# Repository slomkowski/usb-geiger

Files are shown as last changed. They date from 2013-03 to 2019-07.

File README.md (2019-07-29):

# USB Geiger counter

2013 Michał Słomkowski

License: GNU GPL v3.0.

This is a repository of a low-cost USB Geiger counter device using STS-5 tube, ATTiny24 and Python-written host software.

Results can be sent to MySQL database, CSV file, ~~xively.com~~ or defined e-mail address if the radiation level is above the defined threshold.

Project was published in Polish hobby electronics periodic: *Elektronika dla Wszystkich* 10/2013, the article [available here](https://serwis.avt.pl/manuals/AVT3074.pdf).

The repository contains:
* *datasheets* - datasheets of components used in the device, especially the Geiger tube
* *firmare* - source code of firmware for ATTiny24, written in C
* *host/geiger-controller* - simple program in C++ for reading data and writing the settings to the device
* *host/geiger-manager* - more complex software written in Python. Periodically reads the data from sensor and sends them to MySQL or CSV file
* *pcb* - printed circuit board layout in Eagle format, schematic in PNG and mirrored board layout for toner transfer

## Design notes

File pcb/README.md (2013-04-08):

USB Geiger counter
==================

2013 Michał Słomkowski

License: GNU GPL v3.0.

This directory holds circuit board files created in Eagle 6 as well as result files: PDF with mirror image and PNG schematic.

Warning! You need commercial version of Eagle to modify the board. Using freeware version, you may be only able to move elements within area of 80 x 100 mm. This restriction doesn't apply to other tasks like printing, exporting or value changing, though.

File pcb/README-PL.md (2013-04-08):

USB Geiger counter
==================

2013 Michał Słomkowski

Licencja GNU GPL wersja 3.0.

Tu znajdują się pliki płytki drukowanej w Eagle wraz z danymi finalnymi: schematem i lustrzanym PDF-em ze wzorem płytki (potrzebnym do termotransferu).

Uwaga! Płytkę można modyfikować tylko w obszarze 80 x 100 mm używając darmowej wersji, więc ewentualne zmiany mogą wymagać komercyjnej wersji Eagle. Ograniczenie nie dotyczy drukowania, eksportu czy zmiany wartości elementów.

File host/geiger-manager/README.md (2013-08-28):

Geiger Manager
==============
2013 Michał Słomkowski
License: GNU General Public License ver.3

This program is a daemon which monitors constantly the radiation measured by USB Geiger device and sends the results to xively.com, MySQL database, CSV file or e-mail. All configuration is stored in the file 'configuration.ini' which is essential to run. Program uses pyusb library and MySQLdb, if MySQL is enabled.

Optional arguments:
*  -h, --help            show this help message and exit
* -c CONFIG, --config CONFIG
                        reads given configuration file
*  -v, --verbose         shows additional information
*  -b, --background      runs as background process
*  -m, --monitor         starts program in monitor mode
*  -s, --status          reads data from Geiger device and leaves (enabled by
                        default)

To start measuring as a daemon, type:
python2 main.py -mb

geiger.sh is a startup script for Debian and derivative systems (like Raspbian). View that file and read the description within to get to know how to use it.

Running on Windows
==================

This program needs Python 2.7 and libraries: pyusb, libusb and MySQL-python if MySQL module will be used.

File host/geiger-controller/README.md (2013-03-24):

USB Geiger counter
2013 Michał Słomkowski

License: GNU GPL v3.0.

Program provides simple command-line interface to all functions of Geiger device. To display the full list, type:

./geiger-controller --help

The program was written in C++ and libusbx, which is a fork of libusb-1.0 and should stay compatible with it. The code was compiled and run on Linux box, but there's should be no problems with running it on Windows. The program is finished, for more advanced functions like logging to cosm.com or SQL database, check Python script in other directory.

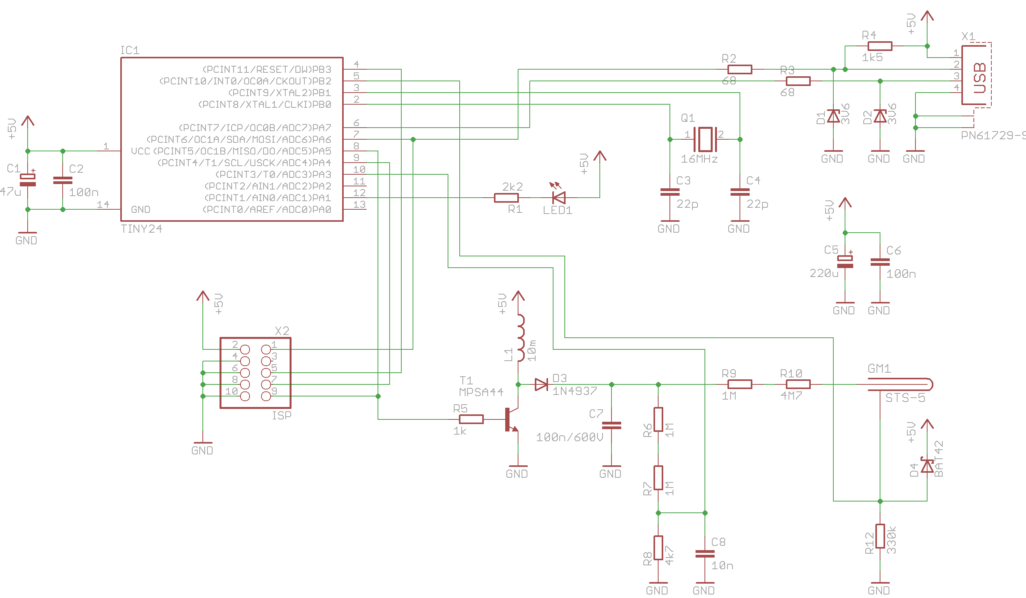
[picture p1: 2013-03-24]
pcb/schematic.png

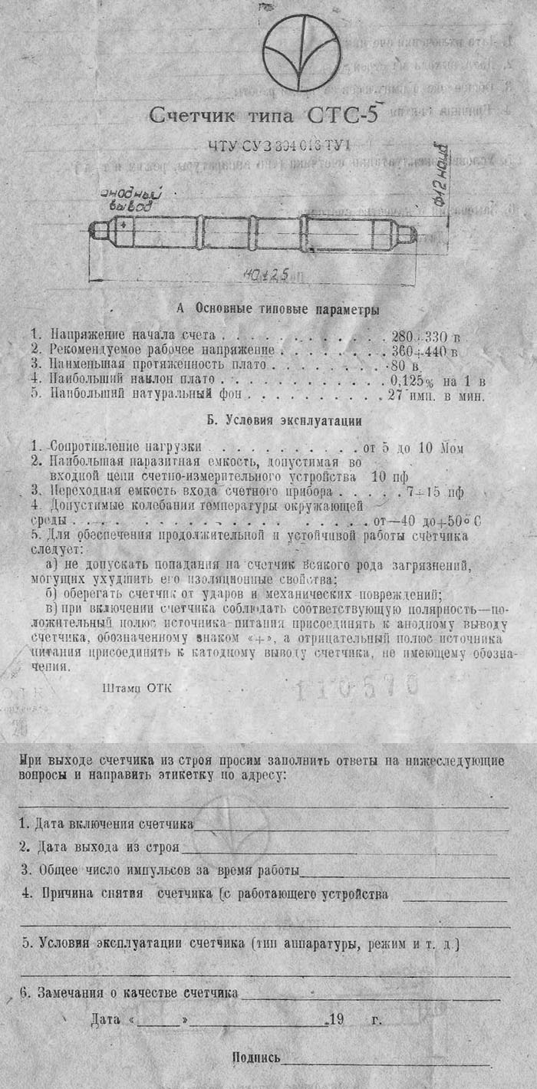
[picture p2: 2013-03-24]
datasheets/sts-5.jpg

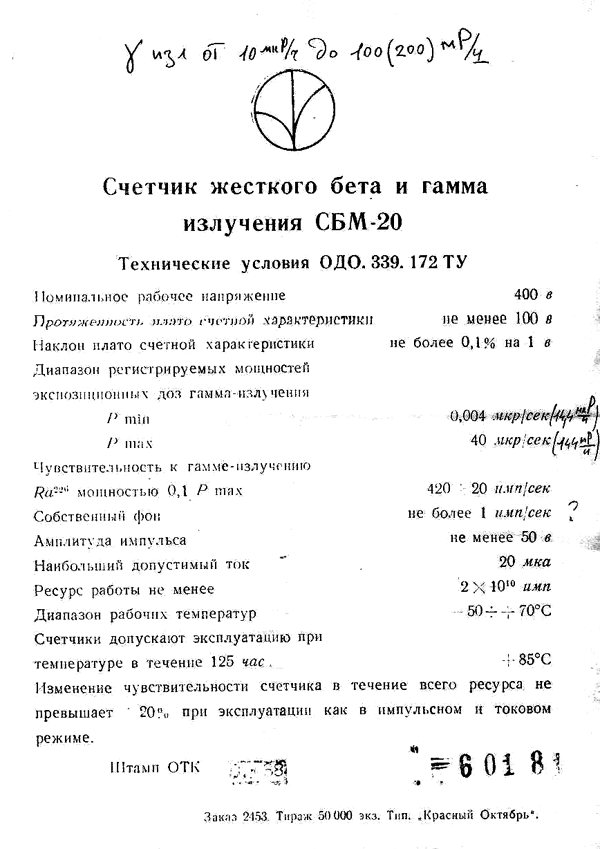
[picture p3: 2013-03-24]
datasheets/sbm-20.png

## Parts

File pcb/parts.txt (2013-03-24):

Partlist

Exported from usb-geiger.sch at 24-03-2013 21:28

EAGLE Version 6.4.0 Copyright (c) 1988-2013 CadSoft

Assembly variant: 

Part     Value          Device            Package      Library  Sheet

C1       47u            CPOL-EUE2.5-6     E2,5-6       rcl      1
C2       100n           C-EU050-025X075   C050-025X075 rcl      1
C3       22p            C-EU025-025X050   C025-025X050 rcl      1
C4       22p            C-EU025-025X050   C025-025X050 rcl      1
C5       220u           CPOL-EUE5-10.5    E5-10,5      rcl      1
C6       100n           C-EU050-025X075   C050-025X075 rcl      1
C7       100n/600V      C-EU225-113X268   C225-113X268 rcl      1
C8       10n            C-EU050-025X075   C050-025X075 rcl      1
D1       3V6            ZENER-DIODEDO34-7 DO34Z7       diode    1
D2       3V6            ZENER-DIODEDO34-7 DO34Z7       diode    1
D3       1N4937         1N4933            DO41-10      diode    1
D4       BAT42          BAT42             DO35-10      diode    1
GM1      STS-5          STS-5             STS-5        geiger   1
IC1      TINY24         TINY24/44/84-PU   DIL14        avr-7    1
L1       10m            L-US0207/5V       0207/5V      rcl      1
LED1                    LED3MM            LED3MM       led      1
Q1       16MHz          XTAL/S            QS           special  1
R1       2k2            R-EU_0207/10      0207/10      rcl      1
R2       68             R-EU_0207/10      0207/10      rcl      1
R3       68             R-EU_0207/10      0207/10      rcl      1
R4       1k5            R-EU_0207/10      0207/10      rcl      1
R5       1k             R-EU_0207/10      0207/10      rcl      1
R6       1M             R-EU_0207/10      0207/10      rcl      1
R7       1M             R-EU_0207/10      0207/10      rcl      1
R8       4k7            R-EU_0207/10      0207/10      rcl      1
R9       1M             R-EU_0207/10      0207/10      rcl      1
R10      4M7            R-EU_0207/10      0207/10      rcl      1
R12      330k           R-EU_0207/10      0207/10      rcl      1
T1       MPSA44         MPSA44            TO92-EBC     geiger   1
X1       PN61729-S      PN61729-S         PN61729-S    con-berg 1
X2                      PINHD-2X5         2X05         pinhead  1

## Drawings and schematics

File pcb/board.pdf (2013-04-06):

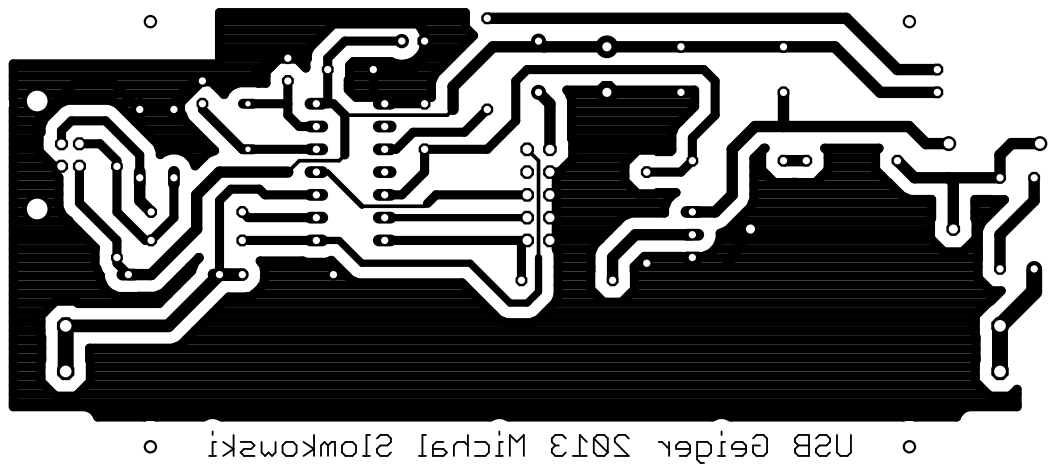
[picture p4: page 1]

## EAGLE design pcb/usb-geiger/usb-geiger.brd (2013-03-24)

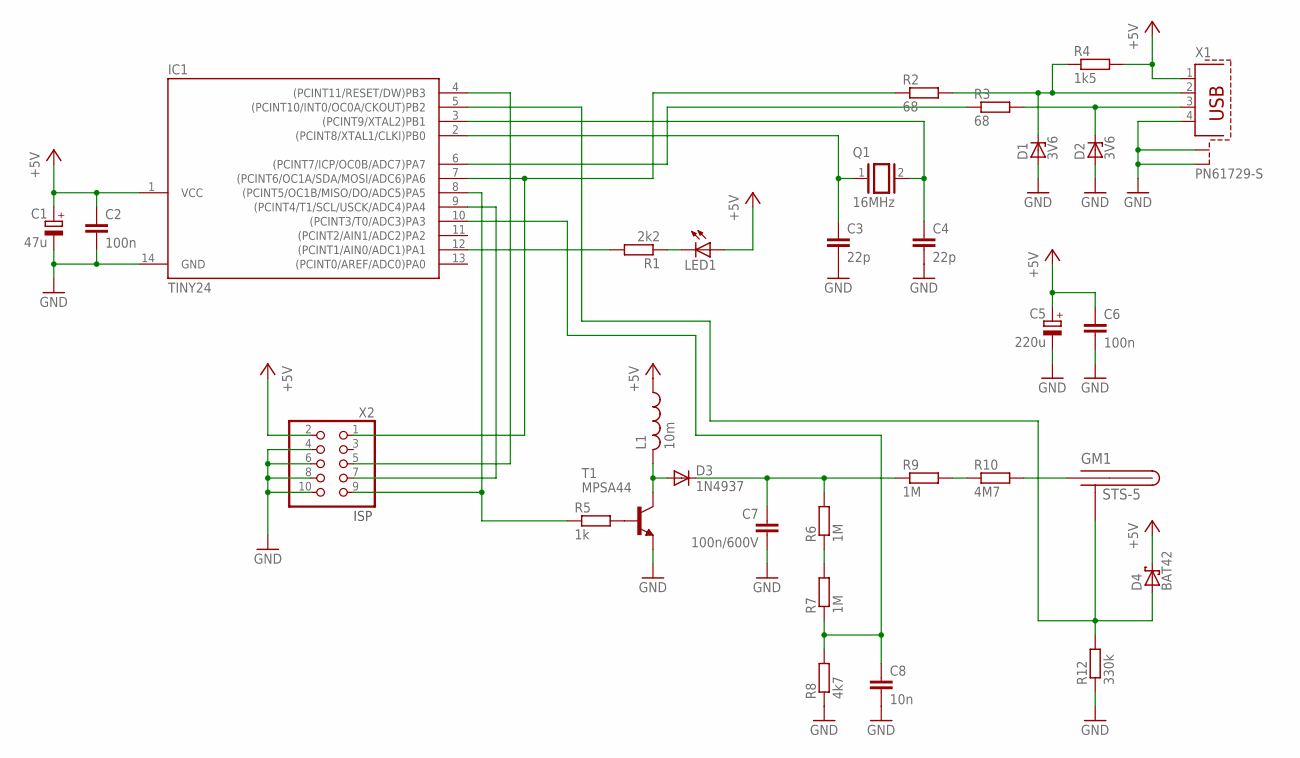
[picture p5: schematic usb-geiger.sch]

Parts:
C1: 47u; E2,5-6
C2, C6: 100n; C050-025X075
C3, C4: 22p; C025-025X050
C5: 220u; E5-10,5
C7: 100n/600V; C225-113X268
C8: 10n; C050-025X075
D1, D2: 3V6; DO34Z7
D3: 1N4937; DO41-10
D4: BAT42; DO35-10
GM1: STS-5
IC1: TINY24; DIL14
L1: 10m; 0207/5V
LED1: LED3MM
Q1: 16MHz; QS
R1: 2k2; 0207/10
R2, R3: 68; 0207/10
R4: 1k5; 0207/10
R5: 1k; 0207/10
R6, R7, R9: 1M; 0207/10
R8: 4k7; 0207/10
R10: 4M7; 0207/10
R12: 330k; 0207/10
T1: MPSA44; TO92-EBC
X1: PN61729-S
X2: PINHD-2X5; 2X05

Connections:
+5V: C1.+, C2.1, C5.+, C6.1, D4.C, IC1.1 (VCC), L1.1, LED1.A, R4.2, X1.1, X2.2
GND: C1.-, C2.2, C3.2, C4.2, C5.-, C6.2, C7.2, C8.2, D1.A, D2.A, IC1.14 (GND), R8.1, R12.1, T1.E, X1.4, X1.S1, X1.S2, X2.4, X2.6, X2.8, X2.10
unnamed: R6.1, R7.2
unnamed: D3.A, L1.2, T1.C
unnamed: R5.2, T1.B
unnamed: C7.1, D3.C, R6.2, R9.1
unnamed: R9.2, R10.1
unnamed: GM1.PLUS1 (PLUS), GM1.PLUS2 (PLUS), R10.2
unnamed: C8.1, IC1.10 ((PCINT3/T0/ADC3)PA3), R7.1, R8.2
unnamed: IC1.6 ((PCINT7/ICP/OC0B/ADC7)PA7), R3.1
unnamed: D4.A, GM1.MINUS1 (MINUS), GM1.MINUS2 (MINUS), IC1.5 ((PCINT10/INT0/OC0A/CKOUT)PB2), R12.2
unnamed: IC1.8 ((PCINT5/OC1B/MISO/DO/ADC5)PA5), R5.1, X2.9
unnamed: IC1.7 ((PCINT6/OC1A/SDA/MOSI/ADC6)PA6), R2.1, X2.1
unnamed: IC1.4 ((PCINT11/RESET/DW)PB3), X2.5
unnamed: IC1.9 ((PCINT4/T1/SCL/USCK/ADC4)PA4), X2.7
unnamed: D1.C, R2.2, R4.1, X1.2
unnamed: D2.C, R3.2, X1.3
unnamed: C4.1, IC1.3 ((PCINT9/XTAL2)PB1), Q1.2
unnamed: C3.1, IC1.2 ((PCINT8/XTAL1/CLKI)PB0), Q1.1
unnamed: IC1.12 ((PCINT1/AIN0/ADC1)PA1), R1.2
unnamed: LED1.K (C), R1.1

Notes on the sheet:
ISP

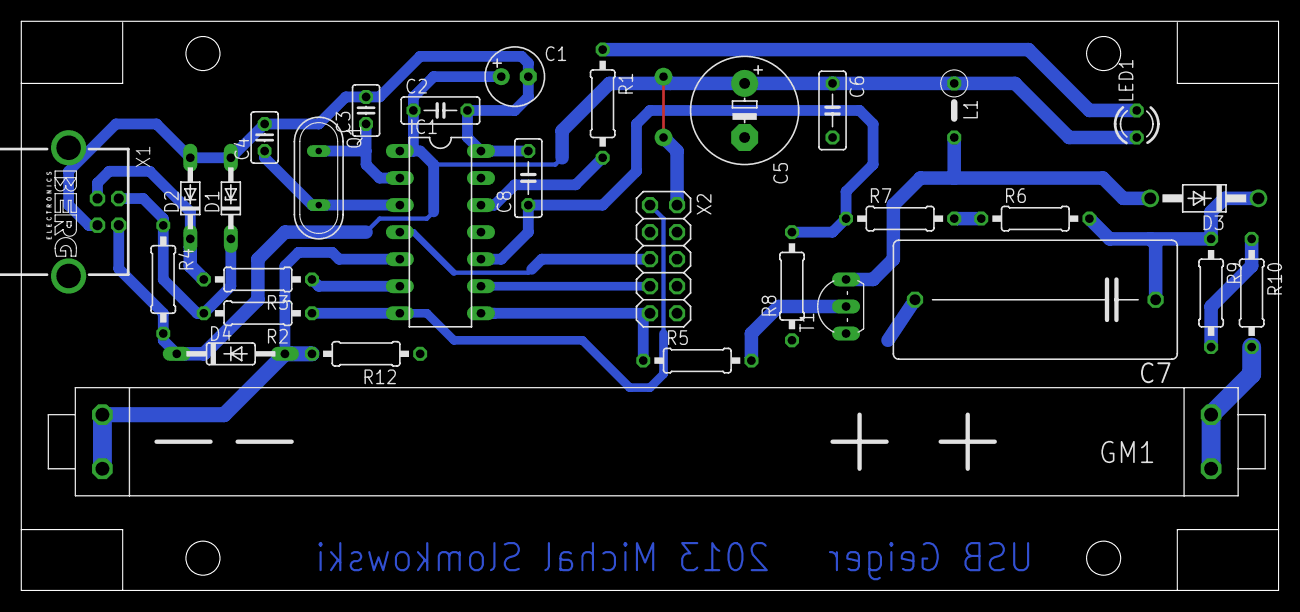
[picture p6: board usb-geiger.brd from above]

Board: 2 copper layers, 118.1 x 53.5 mm, 31 parts (0 on the bottom side), 21 nets.

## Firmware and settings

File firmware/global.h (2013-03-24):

/*
 * USB Geiger counter
 * 2013 Michał Słomkowski
 * This code is distributed under the terms of GNU General Public License version 3.0.
 */

#ifndef _GLOBAL_H_
#define _GLOBAL_H_

#ifndef __ASSEMBLER__

#include <stdbool.h>
#include <inttypes.h>
#endif

#include <avr/io.h>

#define PORT(x) XPORT(x)
#define XPORT(x) (PORT##x)
// *** Pin
#define PIN(x) XPIN(x)
#define XPIN(x) (PIN##x)
// *** DDR
#define DDR(x) XDDR(x)
#define XDDR(x) (DDR##x)

#define F_CPU 16000000UL

// LED
#define led_init() (DDRA |= (1 << PA1))
#define led_on() (PORTA &= ~(1 << PA1))
#define led_off() (PORTA |= (1 << PA1))
#define led_is_off() (!(PINA & (1 << PA1)))
#define led_is_on() (PINA & (1 << PA1))

#define DEFAULT_INTERVAL_SECONDS 60
#define DEFAULT_GEIGER_VOLTAGE 395

#define LED_BLINK_TIME 100 // in milliseconds
#endif

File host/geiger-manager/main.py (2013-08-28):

#!/usr/bin/python2
# -*- encoding: utf-8 -*-
'''
 * USB Geiger counter manager
 * 2013 Michał Słomkowski
 * This code is distributed under the terms of GNU General Public License version 3.0.
'''

import argparse
import ConfigParser
import usbcomm
import sys
import os
import signal
import time
import logging

__version__ = '1.1'
__author__ = 'Michał Słomkowski'
__copyright__ = 'GNU GPL v.3.0'

# default config file name
CONFIG_FILE_NAME = 'configuration.ini'
# directories with configuration file
CONFIG_PATH = [".", os.path.dirname(__file__), os.path.expanduser("~/.geiger"), "/etc/geiger"]

CONFIG_PATH = [os.path.realpath(os.path.join(directory, CONFIG_FILE_NAME)) for directory in CONFIG_PATH]

def signalHandler(signum, frame):
	"""Handles stopping signals, closes all updaters and threads and exits."""
	if args.monitor:
		global logger
		logger.info("Catched signal no. %d, stopping.", signum)
		global monitor
		monitor.stop()
		logging.shutdown()
		sys.exit(1)

# parse command-line arguments
description = "Geiger manager v. " + __version__ + ', ' + __author__ + ". "
description += """This program is a daemon which monitors constantly the radiation measured by USB Geiger device
and sends the results to cosm.com, MySQL database or CSV file. All configuration is stored in the file '"""
description += CONFIG_FILE_NAME + """' which is essential to run. Program uses pyusb library and MySQLdb, if MySQL is enabled."""

parser = argparse.ArgumentParser(description = description)
parser.add_argument("-c", "--config", nargs = 1, help = "reads given configuration file")
parser.add_argument("-v", "--verbose", action = 'store_true', help = "shows additional information")
parser.add_argument("-b", "--background", action = 'store_true', help = "runs as background process")
group = parser.add_mutually_exclusive_group()
group.add_argument("-m", "--monitor", action = 'store_true', help = "starts program in monitor mode")
group.add_argument("-s", "--status", action = 'store_true', help = "reads data from Geiger device and leaves (enabled by default)")

args = parser.parse_args()

if args.verbose and not args.background:
	print("Geiger manager v. " + __version__ + ', ' + __author__)

# become a daemon and fork
if args.background:
	if os.fork() != 0:
		os._exit(0)

if args.config:
	CONFIG_PATH = []
	CONFIG_PATH.append(args.config[0])
	if args.verbose and not args.background:
		print("Using configuration file '%s'" % args.config[0])

# load configuration file
conf = ConfigParser.SafeConfigParser()

for filePath in CONFIG_PATH:
	try:
		conf.readfp(open(filePath))
		configurationLoaded = True
		if args.verbose and not args.background:
			print("Configuration file loaded from: " + filePath)
		break
	except IOError:
		configurationLoaded = False

if not configurationLoaded:
	print >> sys.stderr, ("Error at loading configuration file.")
	sys.exit(1)

try:
	loggingEnabled = conf.getboolean('general', 'log_enabled')
	logFilePath = conf.get('general', 'log_file')
except ConfigParser.Error as exp:
	print >> sys.stderr, ("Could not load logging options: %s" % str(exp))
	sys.exit(1)

logger = logging.getLogger("geiger")
logFormatter = logging.Formatter('%(asctime)s %(name)s %(message)s', datefmt = '[%Y-%m-%d %H:%M:%S]')
if args.verbose:
	logger.setLevel(logging.INFO)
else:
	logger.setLevel(logging.ERROR)

if not args.background:
	consoleLog = logging.StreamHandler(sys.stdout)
	consoleLog.setFormatter(logFormatter)
	logger.addHandler(consoleLog)

if not args.monitor:
	loggingEnabled = False

if loggingEnabled:
	try:
		fileLog = logging.FileHandler(logFilePath)
		fileLog.setFormatter(logFormatter)
		logger.addHandler(fileLog)
	except IOError as exp:
		print >> sys.stderr, ("Could open log file to write: %s" % str(exp))
		sys.exit(1)

# establish USB connection
try:
	logger.info("Initializing Geiger device...")
	comm = usbcomm.Connector(conf)
except usbcomm.CommException as exp:
	logger.critical("Error at initializing USB device: %s", str(exp))
	sys.exit(1)

# register SIGINT (Ctrl-C) signal handler
signal.signal(signal.SIGINT, signalHandler)
signal.signal(signal.SIGTERM, signalHandler)

# start monitor mode
if args.monitor:
	import monitor
	monitor = monitor.Monitor(configuration = conf, usbcomm = comm)
	monitor.start()

	while True:
		time.sleep(5)

# default behavior: display values from Geiger device and leave
print(comm)
sys.exit()

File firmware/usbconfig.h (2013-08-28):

/*
 * USB Geiger counter
 * 2013 Michał Słomkowski
 * This code is distributed under the terms of GNU General Public License version 3.0.
 *
 * This code is based on project: hid-custom-rq example from V-USB created by obdev.com
 */

/* Name: usbconfig.h
 * Project: V-USB, virtual USB port for Atmel's(r) AVR(r) microcontrollers
 * Author: Christian Starkjohann
 * Creation Date: 2005-04-01
 * Tabsize: 4
 * Copyright: (c) 2005 by OBJECTIVE DEVELOPMENT Software GmbH
 * License: GNU GPL v2 (see License.txt), GNU GPL v3 or proprietary (CommercialLicense.txt)
 */

#ifndef __usbconfig_h_included__
#define __usbconfig_h_included__

#include "global.h"

/*
 General Description:
 This file is an example configuration (with inline documentation) for the USB
 driver. It configures V-USB for USB D+ connected to Port D bit 2 (which is
 also hardware interrupt 0 on many devices) and USB D- to Port D bit 4. You may
 wire the lines to any other port, as long as D+ is also wired to INT0 (or any
 other hardware interrupt, as long as it is the highest level interrupt, see
 section at the end of this file).
 */

/* ---------------------------- Hardware Config ---------------------------- */

#define USB_CFG_IOPORTNAME      A

/* This is the port where the USB bus is connected. When you configure it to
 * "B", the registers PORTB, PINB and DDRB will be used.
 */
#define USB_CFG_DMINUS_BIT      6
/* This is the bit number in USB_CFG_IOPORT where the USB D- line is connected.
 * This may be any bit in the port.
 */
#define USB_CFG_DPLUS_BIT       7
/* This is the bit number in USB_CFG_IOPORT where the USB D+ line is connected.
 * This may be any bit in the port. Please note that D+ must also be connected
 * to interrupt pin INT0! [You can also use other interrupts, see section
 * "Optional MCU Description" below, or you can connect D- to the interrupt, as
 * it is required if you use the USB_COUNT_SOF feature. If you use D- for the
 * interrupt, the USB interrupt will also be triggered at Start-Of-Frame
 * markers every millisecond.]
 */
#define USB_CFG_CLOCK_KHZ       (F_CPU/1000)
/* Clock rate of the AVR in kHz. Legal values are 12000, 12800, 15000, 16000,
 * 16500, 18000 and 20000. The 12.8 MHz and 16.5 MHz versions of the code
 * require no crystal, they tolerate +/- 1% deviation from the nominal
 * frequency. All other rates require a precision of 2000 ppm and thus a
 * crystal!
 * Since F_CPU should be defined to your actual clock rate anyway, you should
 * not need to modify this setting.
 */
#define USB_CFG_CHECK_CRC       0
/* Define this to 1 if you want that the driver checks integrity of incoming
 * data packets (CRC checks). CRC checks cost quite a bit of code size and are
 * currently only available for 18 MHz crystal clock. You must choose
 * USB_CFG_CLOCK_KHZ = 18000 if you enable this option.
 */

/* ----------------------- Optional Hardware Config ------------------------ */

/* #define USB_CFG_PULLUP_IOPORTNAME   D */
/* If you connect the 1.5k pullup resistor from D- to a port pin instead of
 * V+, you can connect and disconnect the device from firmware by calling
 * the macros usbDeviceConnect() and usbDeviceDisconnect() (see usbdrv.h).
 * This constant defines the port on which the pullup resistor is connected.
 */
/* #define USB_CFG_PULLUP_BIT          4 */
/* This constant defines the bit number in USB_CFG_PULLUP_IOPORT (defined
 * above) where the 1.5k pullup resistor is connected. See description
 * above for details.
 */

/* --------------------------- Functional Range ---------------------------- */
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

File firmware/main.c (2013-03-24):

/*
 * USB Geiger counter
 * 2013 Michał Słomkowski
 * This code is distributed under the terms of GNU General Public License version 3.0.
 *
 * This code is based on project: hid-custom-rq example from V-USB created by obdev.com
 */

#include "global.h"

#include <avr/io.h>
#include <avr/wdt.h>
#include <avr/interrupt.h>
#include <util/delay.h>

#include <avr/pgmspace.h>
#include "usbdrv.h"
#include "requests.h"

#include "geiger_supply.h"
#include "geiger_counter.h"

PROGMEM const char usbHidReportDescriptor[22] = { /* USB report descriptor */
0x06, 0x00, 0xff,              // USAGE_PAGE (Generic Desktop)
	0x09, 0x01,                    // USAGE (Vendor Usage 1)
	0xa1, 0x01,                    // COLLECTION (Application)
	0x15, 0x00,                    //   LOGICAL_MINIMUM (0)
	0x26, 0xff, 0x00,              //   LOGICAL_MAXIMUM (255)
	0x75, 0x08,                    //   REPORT_SIZE (8)
	0x95, 0x01,                    //   REPORT_COUNT (1)
	0x09, 0x00,                    //   USAGE (Undefined)
	0xb2, 0x02, 0x01,              //   FEATURE (Data,Var,Abs,Buf)
	0xc0                           // END_COLLECTION
	};
/* The descriptor above is a dummy only, it silences the drivers. The report
 * it describes consists of one byte of undefined data.
 * We don't transfer our data through HID reports, we use custom requests
 * instead.
 */

int main() {
	wdt_enable(WDTO_1S);

	usbInit();
	usbDeviceDisconnect(); // enforce re-enumeration, do this while interrupts are disabled!

	supply_init();
	counter_init();
	led_init();

	sei();
	/* Dirty trick to wait > 250 ms. The ledCounter flag will be set to 0 from interrupt routine TIM0_COMPA
	 * in file geiger_counter.c
	 */
	for (led_off(); led_is_off();); // wait till the led is on

	usbDeviceConnect();

	for (;;) {
		wdt_reset();
		usbPoll();
	}
}

/* ------------------------------------------------------------------------- */

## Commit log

2013-03-24 First commit. Firmware and board completed and tested. C++ host side completed.
    [usb-geiger.brd, usb-geiger.sch]
2013-03-24 Geiger-controller: Fix small error with device recognition.
2013-03-29 Fixed local and UTC time issue.
    [monitor.py]
2013-03-30 Fixed error with non-zeroing timer counter variable. Fixed error with ADC init (code redundant). Code optimizing.
    [geiger_counter.c, geiger_supply.c]
2013-03-31 Added exception handling for USB errors and reconnection in this case.
    [main.py, monitor.py, usbcomm.py]
2013-04-03 Fixed error with wrong starting interval.
    [monitor.py]
2013-04-06 Board new pdf.
2013-04-08 Added README in pcb directory.
2013-04-08 Fix for double updater adding.
    [monitor.py]
2013-08-04 Disabled interrupt endpoint in config - saved many bytes of the result file.
2013-08-11 Reenabled interrupt endpoint for compatibility with USB spec.
2013-08-28 Enabled USB_CFG_SUPRESS_INTR_CODE to disable handling interrupt-in transfers. It saves a couple of bytes of program memory.
